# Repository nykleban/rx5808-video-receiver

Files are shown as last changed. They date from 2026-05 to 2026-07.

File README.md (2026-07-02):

# Smart FPV Analog RX & Spectral Analyzer

**Проєкт:** апаратно-програмний комплекс для прийому аналогового FPV-відеосигналу 5.8 GHz та сканування радіочастотного спектра в реальному часі.

---

## Про Проєкт

Цей репозиторій містить вихідний код прошивки, десктопного додатку та файли проєкту друкованої плати для розумного FPV-приймача. Система побудована на базі мікроконтролера **ATmega328P**, високочастотного модуля **RX5808** та розширеної системи керування живленням для забезпечення стабільних аналогових вимірювань.

Проєкт поєднує низькорівневе програмування вбудованих систем, розробку 4-шарової PCB з високими вимогами до розведення RF, силових та аналогових вузлів, а також десктопний аналізатор на Python. Проєкт розроблено в рамках інженерно-практичної роботи програми робототехніки Інституту ІТ та бізнесу.

Плата спроєктована в KiCad і замовлена через JLCPCB. На момент підготовки репозиторію плата ще не доставлена, тому в репозиторії подані проєктні матеріали: схема, PCB-layout, production-файли, 3D-рендери та скріншоти програмної частини.

---

## Основні Характеристики системи

### Hardware

- **RF-модуль:** приймач **RX5808 5.8 GHz** із керуванням через SPI для вибору частоти.
- **Мікроконтролер:** **ATmega328P** із зовнішнім кварцовим резонатором 16 MHz.
- **Power Management:** контролер заряду **Texas Instruments BQ25703A**, апаратний захист акумулятора **HY2120-CB**, шунти для вимірювання струму.
- **Інтерфейси:** **USB Type-C**, **CP2102N USB-to-UART**, торцевий **SMA edge-mount** роз'єм для FPV-антени.

### Software

- **Firmware C/C++:** прошивка для ATmega328P із керуванням RX5808 через SPI, зчитуванням RSSI через ADC, I2C-взаємодією з BQ25703A та serial logging.
- **Python GUI:** десктопний додаток для візуалізації RSSI в реальному часі та перевірки рівня сигналу на обраній частоті.

---

## Основні можливості

- прийом аналогового FPV-сигналу 5.8 GHz через RX5808;
- перемикання FPV-частот через SPI-керування RX5808;
- зчитування RSSI для оцінки рівня сигналу;
- виведення band, channel, frequency та RSSI через serial log;
- візуалізація RSSI в desktop analyzer у реальному часі;
- підготовлена 4-шарова PCB з окремими RF, MCU та power-management блоками;
- production package для виготовлення плати.

---

## Архітектура Друкованої Плати (PCB Layout)

Плата розроблена як 4-шарова PCB товщиною 1.6 мм з урахуванням суворих правил трасування:

1. **Ізоляція шумів:** силовий імпульсний блок з BQ25703A максимально віддалений від аналогової частини приймача RX5808.
2. **Розділення функціональних блоків:** RF, MCU, USB/UART та power-management частини винесені в окремі зони плати.
3. **Екранування:** GND-полігони використовуються для зменшення шумів і покращення стабільності аналогових вимірювань.
4. **Production-ready структура:** підготовлено BOM, positions, designators, IPC netlist і production archive для виготовлення плати.

---

## Firmware

Прошивка для ATmega328P реалізує:

- SPI-керування RX5808;
- вибір FPV-частоти;
- зчитування RSSI через ADC;
- I2C-взаємодію з power-management контролером;
- serial logging для перевірки каналу, частоти та RSSI.

Файл прошивки: `CODE/fpv_receiver.ino`

---

## Desktop analyzer

Python-додаток використовується для перегляду RSSI в реальному часі. Він дає змогу візуально порівнювати рівень сигналу на різних каналах і бачити стабільність прийому.

Використані технології: Python, PyQt5, pyqtgraph, pyserial, NumPy.

Файл додатку: `CODE/main.py`

---

## Структура репозиторію

```text
.
├── CODE/                         # firmware and desktop analyzer
│   ├── fpv_receiver.ino
│   └── main.py
├── IMAGES/                       # renders, schematics and analyzer screenshots
├── Custom_Libs/                  # custom KiCad symbols and footprints
├── production/                   # BOM, positions, designators, netlist
├── atmega328.kicad_pcb           # PCB layout
├── atmega328.kicad_sch           # main schematic
├── mcu_atmega_spi.kicad_sch      # MCU/SPI schematic block
├── rx5808_rf.kicad_sch           # RF schematic block
├── power_usb_battery_buck.kicad_sch
└── production.zip
```

---

## Візуальні матеріали

### PCB та схема

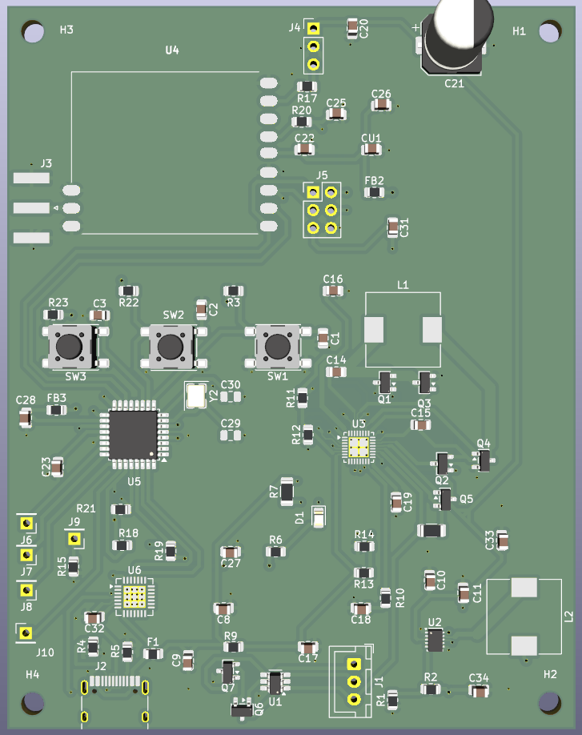
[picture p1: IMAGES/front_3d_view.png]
Front 3D view


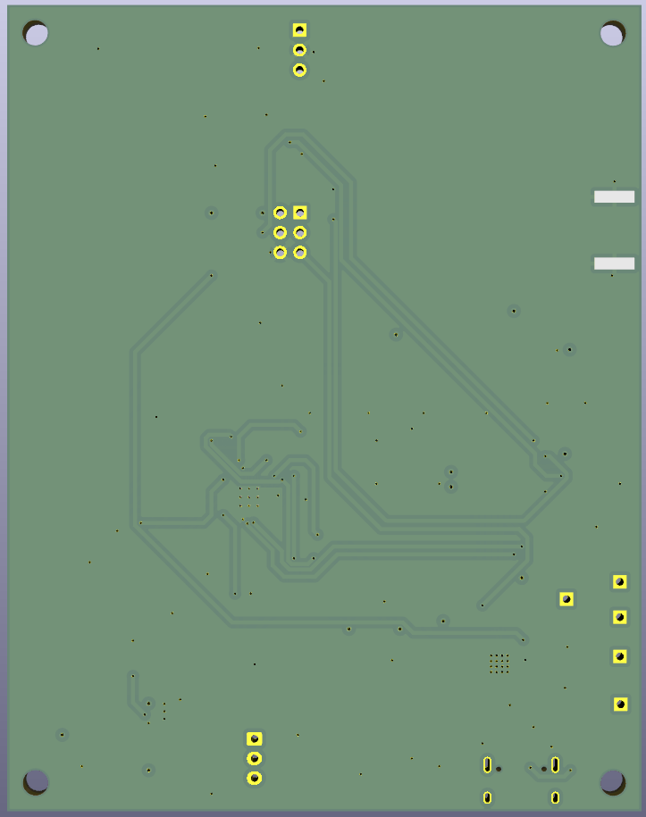
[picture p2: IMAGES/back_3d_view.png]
Back 3D view


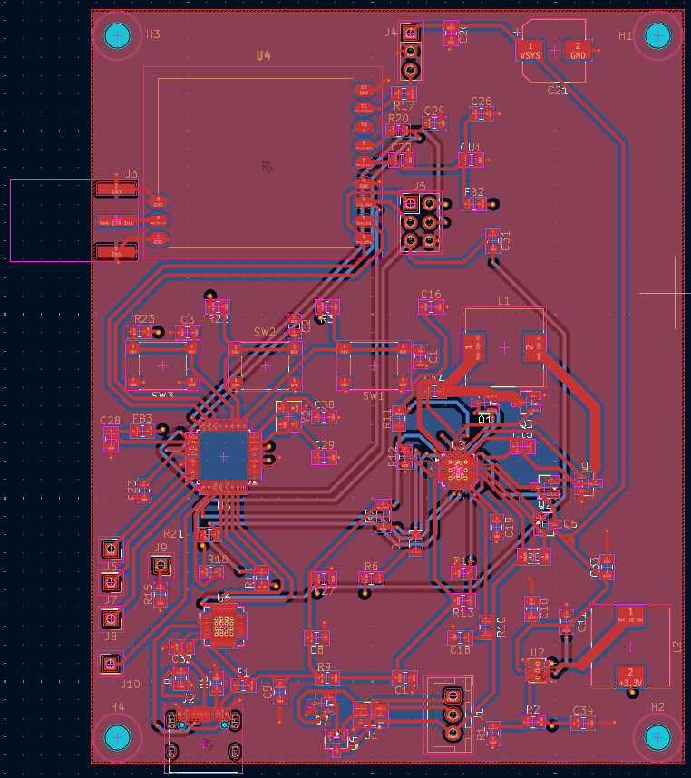
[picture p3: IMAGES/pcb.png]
PCB layout


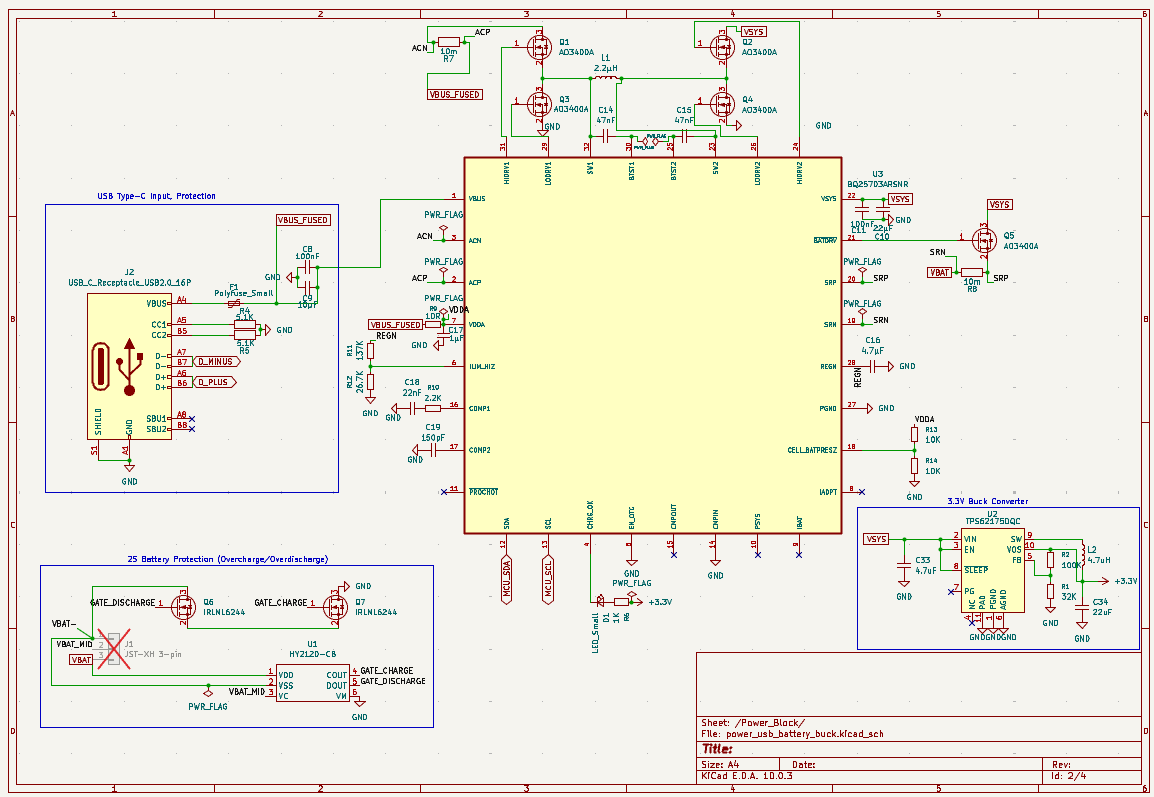
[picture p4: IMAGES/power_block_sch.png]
Power block schematic


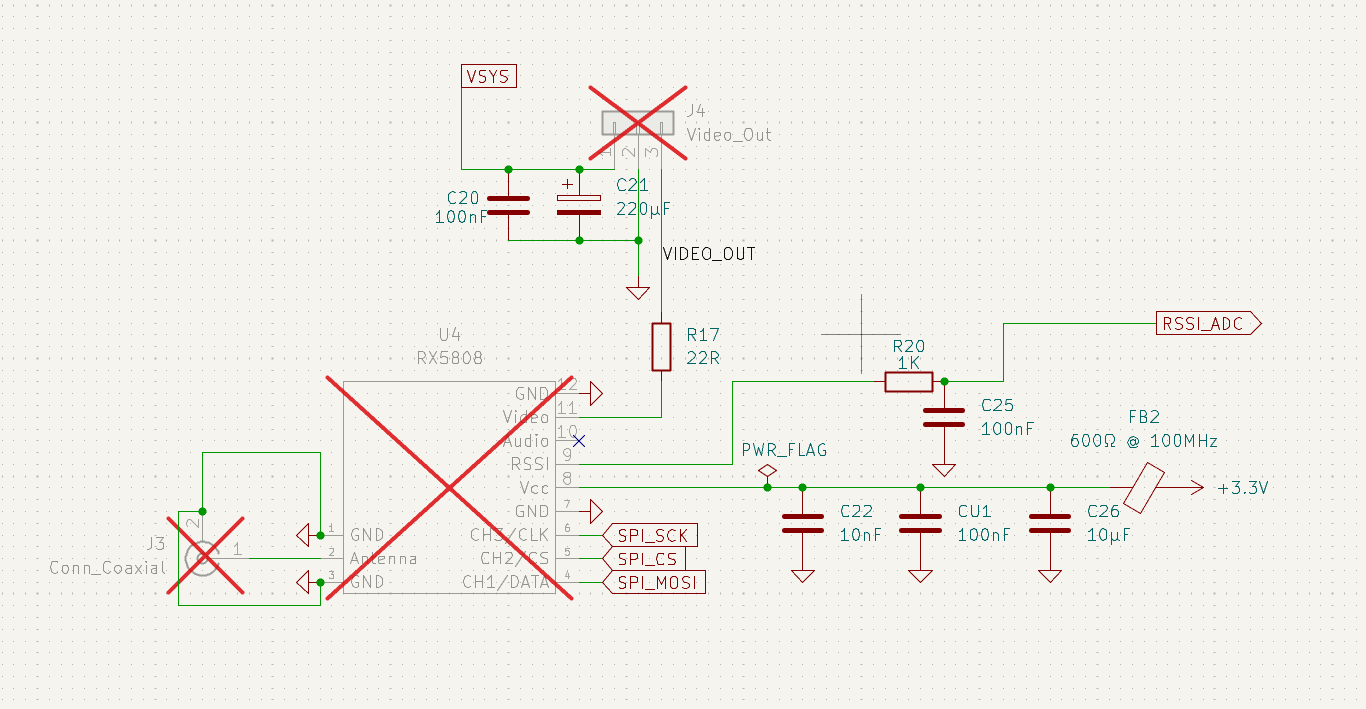
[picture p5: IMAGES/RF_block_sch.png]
RF block schematic


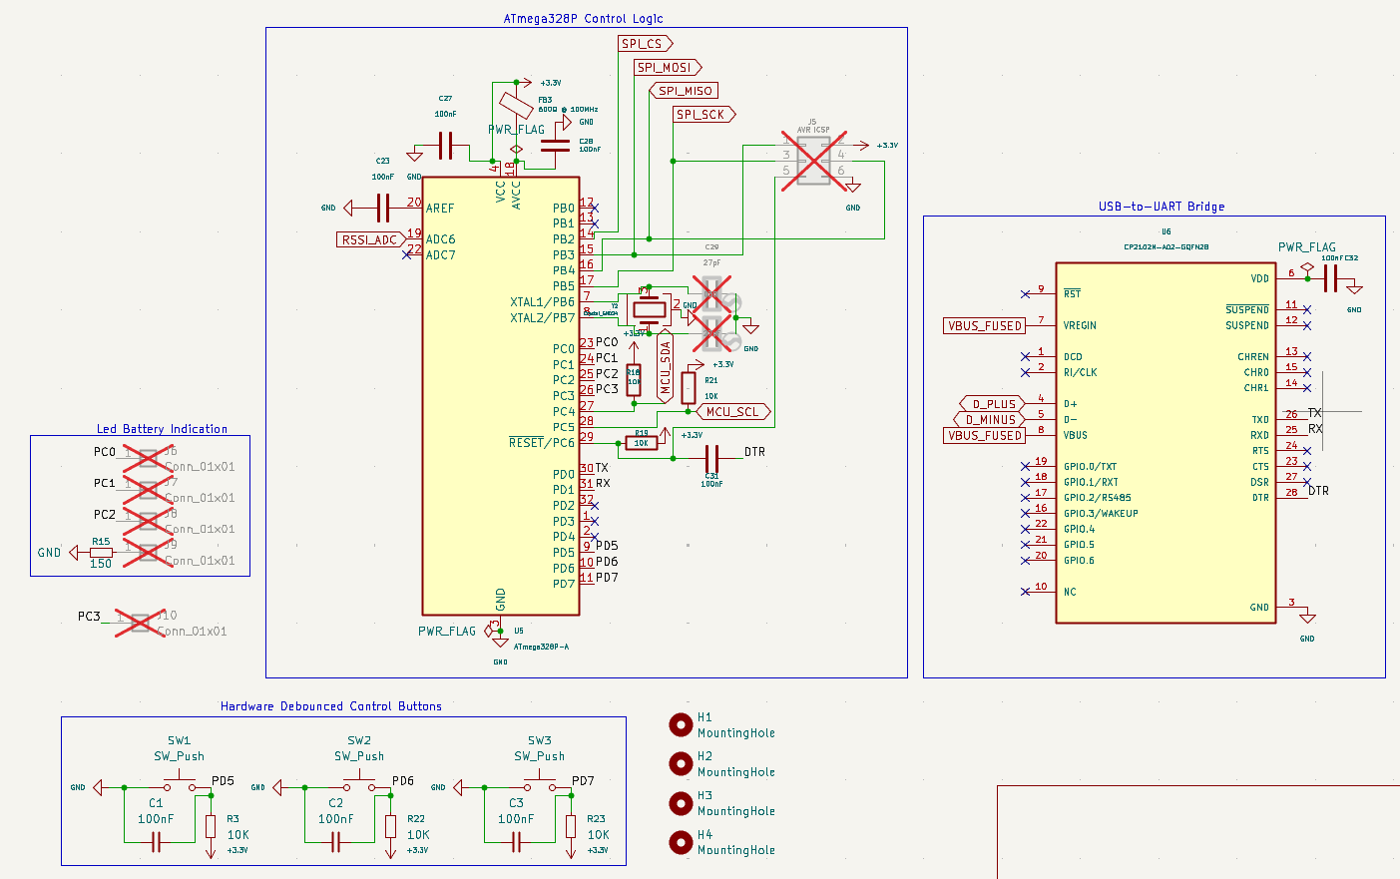
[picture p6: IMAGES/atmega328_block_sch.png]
ATmega328P block schematic


### RSSI analyzer

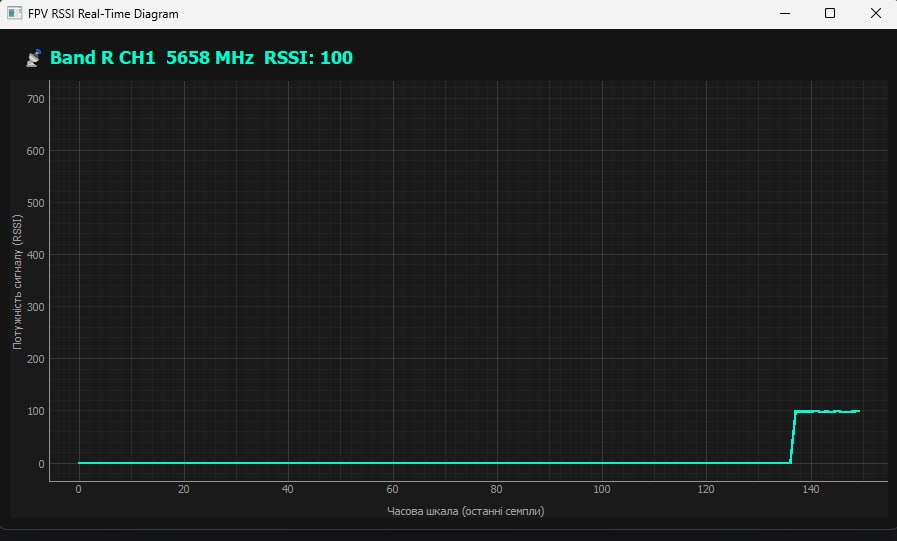
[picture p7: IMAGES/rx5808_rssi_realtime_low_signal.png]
Low signal RSSI


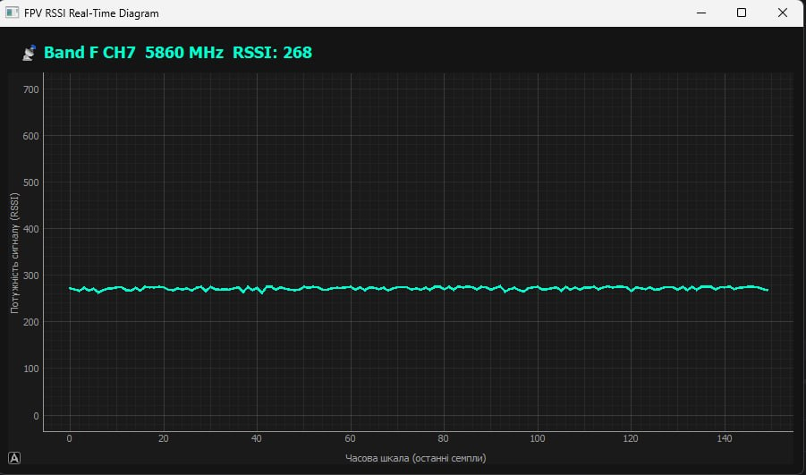
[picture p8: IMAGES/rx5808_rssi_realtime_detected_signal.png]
Detected signal RSSI


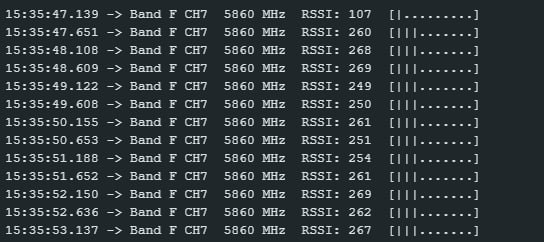
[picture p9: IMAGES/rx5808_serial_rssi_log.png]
Serial RSSI log


---

## Production files

Папка `production/` містить матеріали для виготовлення та перевірки плати:

- `bom.csv`;
- `positions.csv`;
- `designators.csv`;
- `netlist.ipc`;
- `atmega328.zip`.

Також у корені є `production.zip` як готовий архів production package.

---

## Поточний статус

- schematic design completed;
- 4-layer PCB layout completed;
- production files generated;
- PCB ordered through JLCPCB;
- firmware and desktop analyzer added to the repository;
- RSSI analyzer screenshots included.

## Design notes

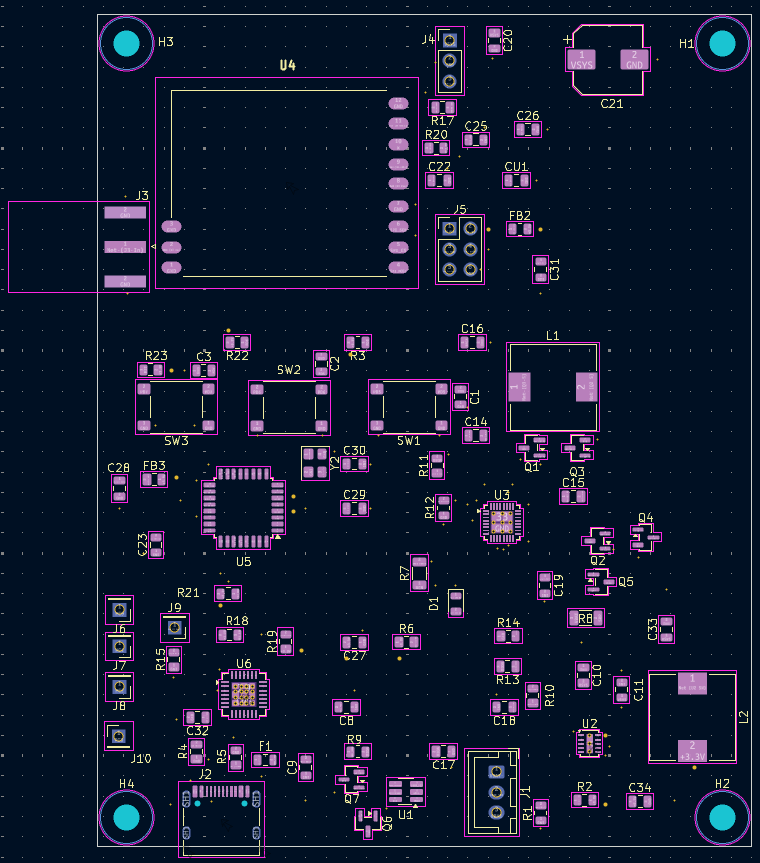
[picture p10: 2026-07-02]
IMAGES/pcb_without_traces.png

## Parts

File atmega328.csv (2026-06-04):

Reference | Value | Footprint | LCSC
C1,C2,C3,C8,C11,C20,C23,C25,C27,C28,C31,C32,CU1 | 100nF | Capacitor_SMD:C_0805_2012Metric | C1711
C9,C26 | 10µF | Capacitor_SMD:C_0805_2012Metric | C7469956
C10 | 22µF | Capacitor_SMD:C_0805_2012Metric | C602037
C14,C15 | 47nF | Capacitor_SMD:C_0805_2012Metric | C53134
C16 | 4.7µF | Capacitor_SMD:C_0805_2012Metric | C98195
C17 | 1µF | Capacitor_SMD:C_0805_2012Metric | C1791
C18 | 22nF | Capacitor_SMD:C_0805_2012Metric | C1729
C19 | 150pF | Capacitor_SMD:C_0805_2012Metric | C2319426
C21 | 220µF | Capacitor_SMD:CP_Elec_8x10 | C136294
C22 | 10nF | Capacitor_SMD:C_0805_2012Metric | C1710
C33 | 4.7uF | Capacitor_SMD:C_0805_2012Metric | C98195
C34 | 22uF | Capacitor_SMD:C_0805_2012Metric | C602037
D1 | LED_Small | LED_SMD:LED_0805_2012Metric | C84260
F1 | Polyfuse_Small | Fuse:Fuse_0805_2012Metric | C2840556
FB2,FB3 | 600Ω @ 100MHz | Resistor_SMD:R_0805_2012Metric | C21519
J1 | JST-XH 3-pin | Connector_JST:JST_XH_B3B-XH-A_1x03_P2.50mm_Vertical
J2 | USB_C_Receptacle_USB2.0_16P | Connector_USB:USB_C_Receptacle_HRO_TYPE-C-31-M-12 | C2988369
J3 | Conn_Coaxial | Connector_Coaxial:SMA_Amphenol_132289_EdgeMount | C20415780
J4 | Video_Out | Connector_PinHeader_2.54mm:PinHeader_1x03_P2.54mm_Vertical
J5 | AVR ICSP | Connector_PinHeader_2.54mm:PinHeader_2x03_P2.54mm_Vertical
J6,J7,J8,J9,J10 | Conn_01x01 | Connector_PinHeader_2.54mm:PinHeader_1x01_P2.54mm_Vertical
L1 | 2.2µH | Inductor_SMD:L_10.4x10.4_H4.8 | C10164
L2 | 4.7uH | Inductor_SMD:L_10.4x10.4_H4.8 | C19633496
Q1,Q2,Q3,Q4,Q5 | AO3400A | Package_TO_SOT_SMD:SOT-23 | C20917
Q6,Q7 | IRLML6244 | Package_TO_SOT_SMD:SOT-23 | C5364311
R1 | 32K | Resistor_SMD:R_0805_2012Metric | C6460768
R2 | 100K | Resistor_SMD:R_0805_2012Metric | C441992
R3,R13,R14,R18,R19,R21,R22,R23 | 10K | Resistor_SMD:R_0805_2012Metric | C543567
R4,R5 | 5.1K | Resistor_SMD:R_0805_2012Metric | C491151
R6 | 1K | Resistor_SMD:R_0805_2012Metric | C844939
R7,R8 | 10m | Resistor_SMD:R_1206_3216Metric | C308574
R9 | 10R | Resistor_SMD:R_0805_2012Metric | C844598
R10 | 2.2K | Resistor_SMD:R_0805_2012Metric | C441982
R11 | 137K | Resistor_SMD:R_0805_2012Metric | C203741
R12 | 26.7K | Resistor_SMD:R_0805_2012Metric | C153307
R15 | 150 | Resistor_SMD:R_0805_2012Metric | C2933324
R17 | 22R | Resistor_SMD:R_0805_2012Metric | C441970
R20 | 1К | Resistor_SMD:R_0805_2012Metric | C844939
SW1,SW2,SW3 | SW_Push | Button_Switch_SMD:SW_SPST_PTS645Sx43SMTR92 | C2834918
U1 | HY2120-CB | Package_TO_SOT_SMD:SOT-23-6_Handsoldering | C116509
U2 | TPS62175DQC | Package_SON:WSON-10-1EP_2x3mm_P0.5mm_EP0.84x2.4mm_ThermalVias | C32097
U3 | BQ25703ARSNR | Package_DFN_QFN:Texas_RSN_WQFN-32-1EP_4x4mm_P0.4mm_EP2.8x2.8mm_ThermalVias | C188229
U4 | RX5808 | RF_Antenna:RX5808
U5 | ATmega328P-A | Package_QFP:TQFP-32_7x7mm_P0.8mm | C14877
U6 | CP2102N-A02-GQFN28 | Package_DFN_QFN:QFN-28-1EP_5x5mm_P0.5mm_EP3.1x3.1mm_ThermalVias | C964632
Y2 | Crystal_GND24 | Crystal:Crystal_SMD_3225-4Pin_3.2x2.5mm | C7275095

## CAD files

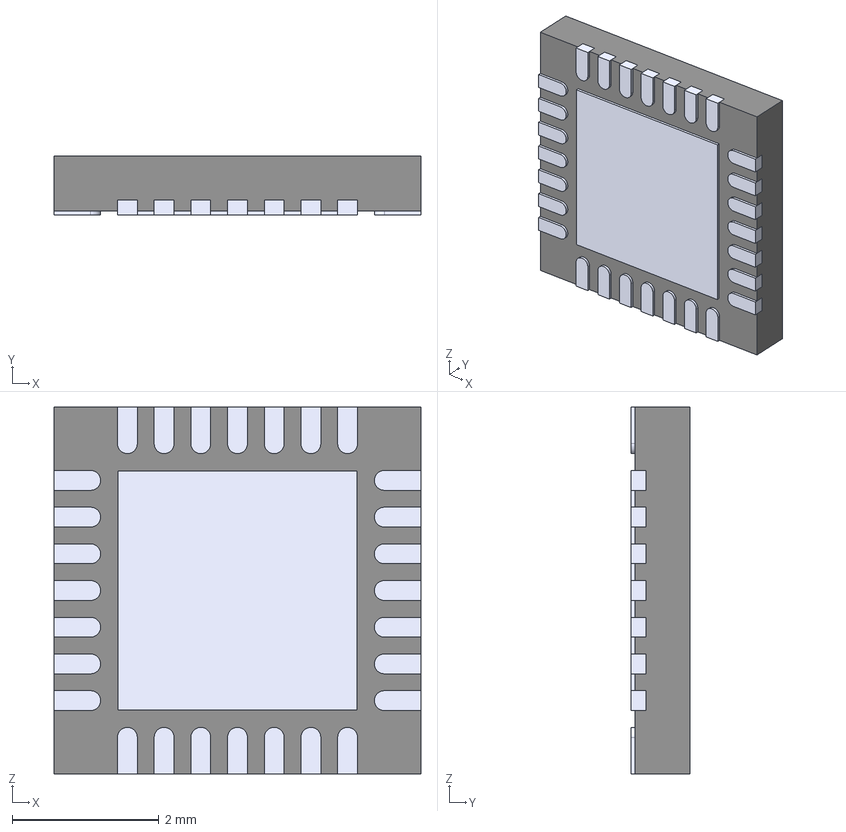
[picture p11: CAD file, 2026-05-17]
CP2102N-A02-GQFN28.step
5.00 x 0.8 x 5.00 mm
Body_Solid1
Body001_Solid1
Array_Solid1 x 7
Array001_Solid2 x 6
Body002_Solid1
Array002_Solid1 x 7
Array003_Solid2 x 6
Body003_Solid1
Body004_Solid1

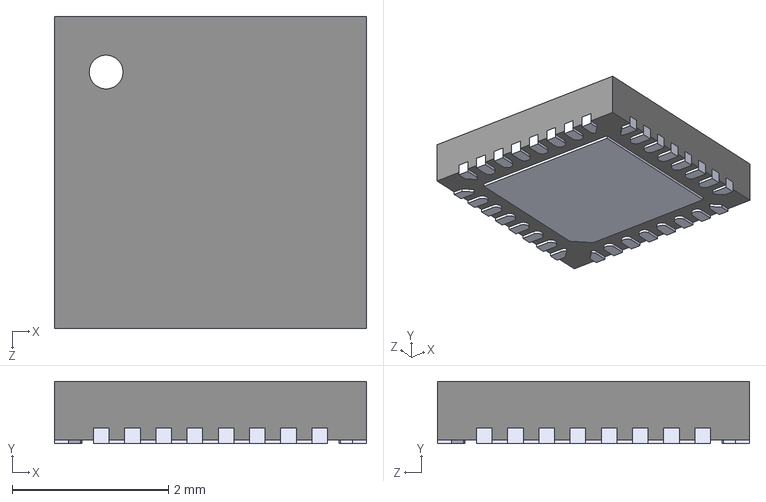
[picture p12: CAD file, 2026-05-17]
Custom_Libs/BQ25703ARSNR.step
4.00 x 0.8 x 4.00 mm

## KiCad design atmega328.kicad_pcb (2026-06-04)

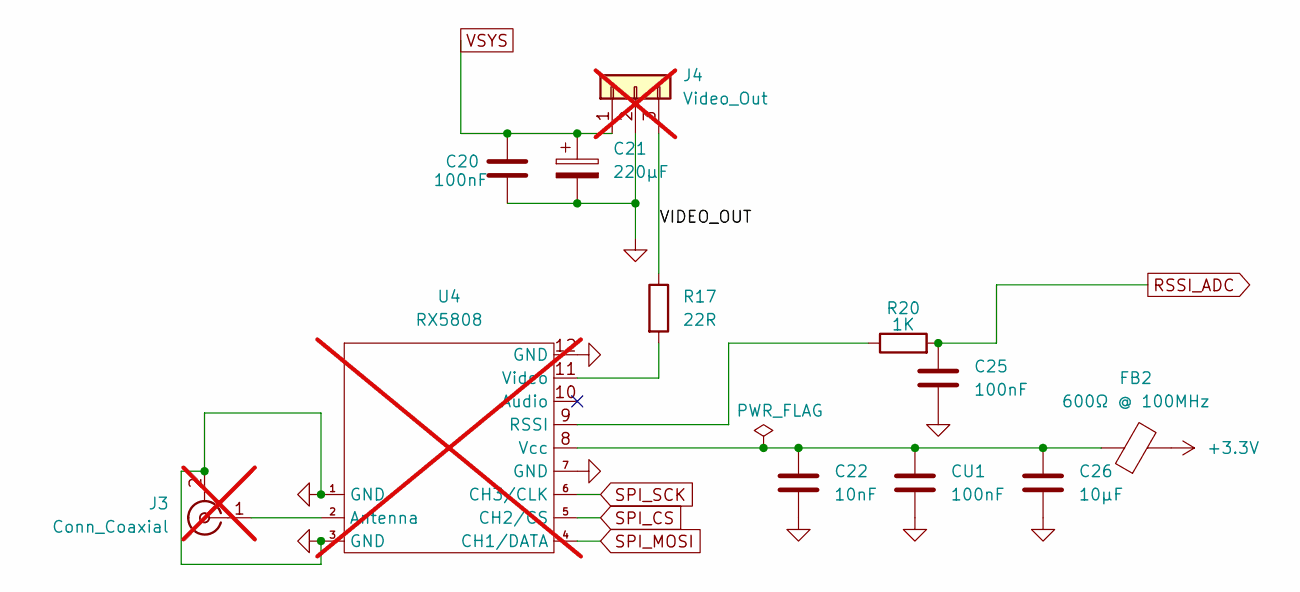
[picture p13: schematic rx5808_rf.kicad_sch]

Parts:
C20, C25: 100nF; C_0805_2012Metric; LCSC C1711
C21: 220µF; CP_Elec_8x10; LCSC C136294
C22: 10nF; C_0805_2012Metric; LCSC C1710
C26: 10µF; C_0805_2012Metric; LCSC C7469956
CU1: 100nF; C_0805_2012Metric; LCSC C1711
FB2: 600Ω @ 100MHz; R_0805_2012Metric; LCSC C21519
J3: Conn_Coaxial; SMA_Amphenol_132289_EdgeMount; LCSC C20415780; not fitted
J4: Video_Out; PinHeader_1x03_P2.54mm_Vertical; not fitted
R17: 22R; R_0805_2012Metric; LCSC C441970
R20: 1К; R_0805_2012Metric; LCSC C844939
U4: RX5808; not fitted

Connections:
+3.3V: FB2.2; also elsewhere on the board
/RX5808/VIDEO_OUT: J4.3, R17.1
GND: C20.2, C21.2, C22.2, C25.2, C26.2, CU1.2, J3.2 (Ext), J4.2, U4.1 (GND), U4.3 (GND), U4.7 (GND), U4.12 (GND); also elsewhere on the board
unnamed: J3.1 (In), U4.2 (Antenna)
unnamed: R20.1, U4.9 (RSSI)
unnamed: C22.1, C26.1, CU1.1, FB2.1, U4.8 (Vcc)
unnamed: R17.2, U4.11 (Video)
RSSI_ADC: C25.1, R20.2; also elsewhere on the board
SPI_CS: U4.5 (CH2/CS); also elsewhere on the board
SPI_MOSI: U4.4 (CH1/DATA); also elsewhere on the board
SPI_SCK: U4.6 (CH3/CLK); also elsewhere on the board
VSYS: C20.1, C21.1, J4.1; also elsewhere on the board

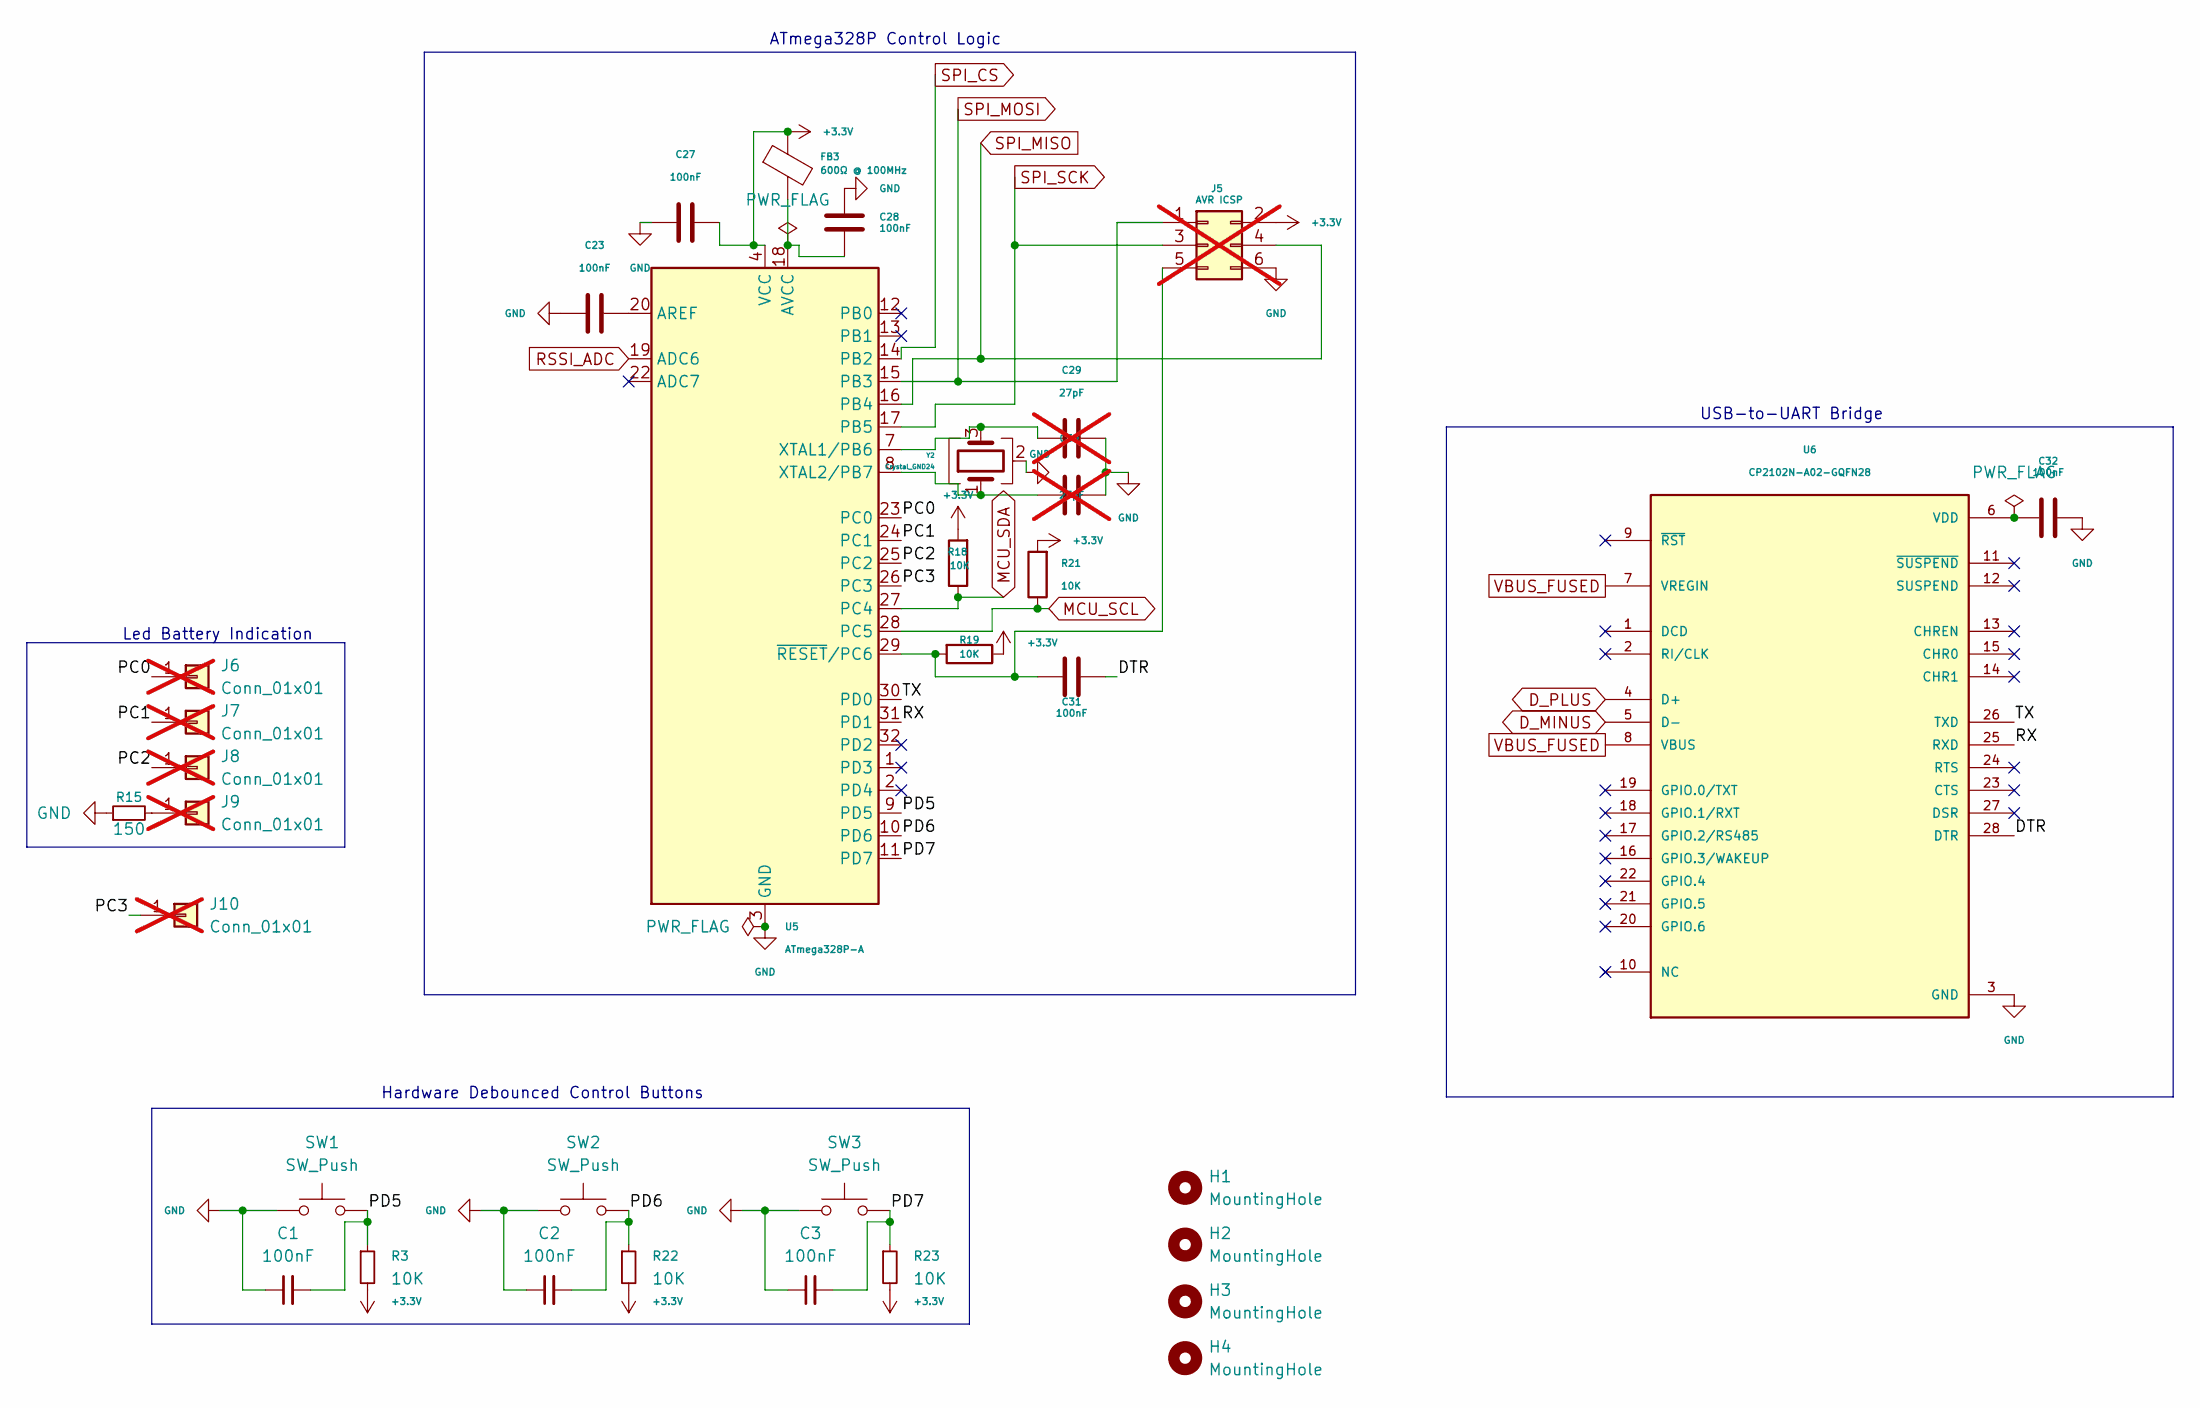
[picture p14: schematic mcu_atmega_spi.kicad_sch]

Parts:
C1, C2, C3, C23, C27, C28, C31, C32: 100nF; C_0805_2012Metric; LCSC C1711
C29, C30: 27pF; C_0805_2012Metric; LCSC C472840; not fitted
FB3: 600Ω @ 100MHz; R_0805_2012Metric; LCSC C21519
H1, H2, H3, H4: MountingHole; MountingHole_3.2mm_M3
J5: AVR ICSP; PinHeader_2x03_P2.54mm_Vertical; not fitted
J6, J7, J8, J9, J10: Conn_01x01; PinHeader_1x01_P2.54mm_Vertical; not fitted
R3, R18, R19, R21, R22, R23: 10K; R_0805_2012Metric; LCSC C543567
R15: 150; R_0805_2012Metric; LCSC C2933324
SW1, SW2, SW3: SW_Push; SW_SPST_PTS645Sx43SMTR92; LCSC C2834918
U5: ATmega328P-A; TQFP-32_7x7mm_P0.8mm; LCSC C14877
U6: CP2102N-A02-GQFN28; QFN-28-1EP_5x5mm_P0.5mm_EP3.1x3.1mm_ThermalVias; PARTREV 1.5; LCSC C964632
Y2: Crystal_GND24; Crystal_SMD_3225-4Pin_3.2x2.5mm; LCSC C7275095

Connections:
+3.3V: C27.2, FB3.1, J5.2, R3.2, R18.2, R19.1, R21.2, R22.2, R23.2, U5.4 (VCC), U5.6 (VCC); also elsewhere on the board
/MCU_Block/DTR: C31.2, U6.28 (DTR)
/MCU_Block/PC0: J6.1 (Pin_1_1), U5.23 (PC0)
/MCU_Block/PC1: J7.1 (Pin_1_1), U5.24 (PC1)
/MCU_Block/PC2: J8.1 (Pin_1_1), U5.25 (PC2)
/MCU_Block/PC3: J10.1 (Pin_1_1), U5.26 (PC3)
/MCU_Block/PD5: C1.2, R3.1, SW1.2, U5.9 (PD5)
/MCU_Block/PD6: C2.2, R22.1, SW2.2, U5.10 (PD6)
/MCU_Block/PD7: C3.2, R23.1, SW3.2, U5.11 (PD7)
/MCU_Block/RX: U5.31 (PD1), U6.25 (RXD)
/MCU_Block/TX: U5.30 (PD0), U6.26 (TXD)
D_MINUS: U6.5 (D-); also elsewhere on the board
D_PLUS: U6.4 (D+); also elsewhere on the board
GND: C1.1, C2.1, C3.1, C23.1, C27.1, C28.2, C29.2, C30.2, C32.2, J5.6, R15.1, SW1.1, SW2.1, SW3.1, U5.3 (GND), U5.5 (GND), U5.21 (GND), U6.3 (GND), U6.29 (GND), Y2.2 (G), Y2.4 (G); also elsewhere on the board
MCU_SCL: R21.1, U5.28 (PC5); also elsewhere on the board
MCU_SDA: R18.1, U5.27 (PC4); also elsewhere on the board
unnamed: C31.1, J5.5, R19.2, U5.29 (~RESET/PC6)
unnamed: J9.1 (Pin_1_1), R15.2
unnamed: C23.2, U5.20 (AREF)
unnamed: C28.1, FB3.2, U5.18 (AVCC)
unnamed: C29.1, U5.7 (XTAL1/PB6), Y2.3
unnamed: C30.1, U5.8 (XTAL2/PB7), Y2.1
unnamed: C32.1, U6.6 (VDD)
RSSI_ADC: U5.19 (ADC6); also elsewhere on the board
SPI_CS: U5.14 (PB2); also elsewhere on the board
SPI_MISO: J5.4, U5.16 (PB4)
SPI_MOSI: J5.1, U5.15 (PB3); also elsewhere on the board
SPI_SCK: J5.3, U5.17 (PB5); also elsewhere on the board
VBUS_FUSED: U6.7 (VREGIN), U6.8 (VBUS); also elsewhere on the board

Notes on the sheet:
ATmega328P Control Logic
Hardware Debounced Control Buttons
Led Battery Indication
USB-to-UART Bridge

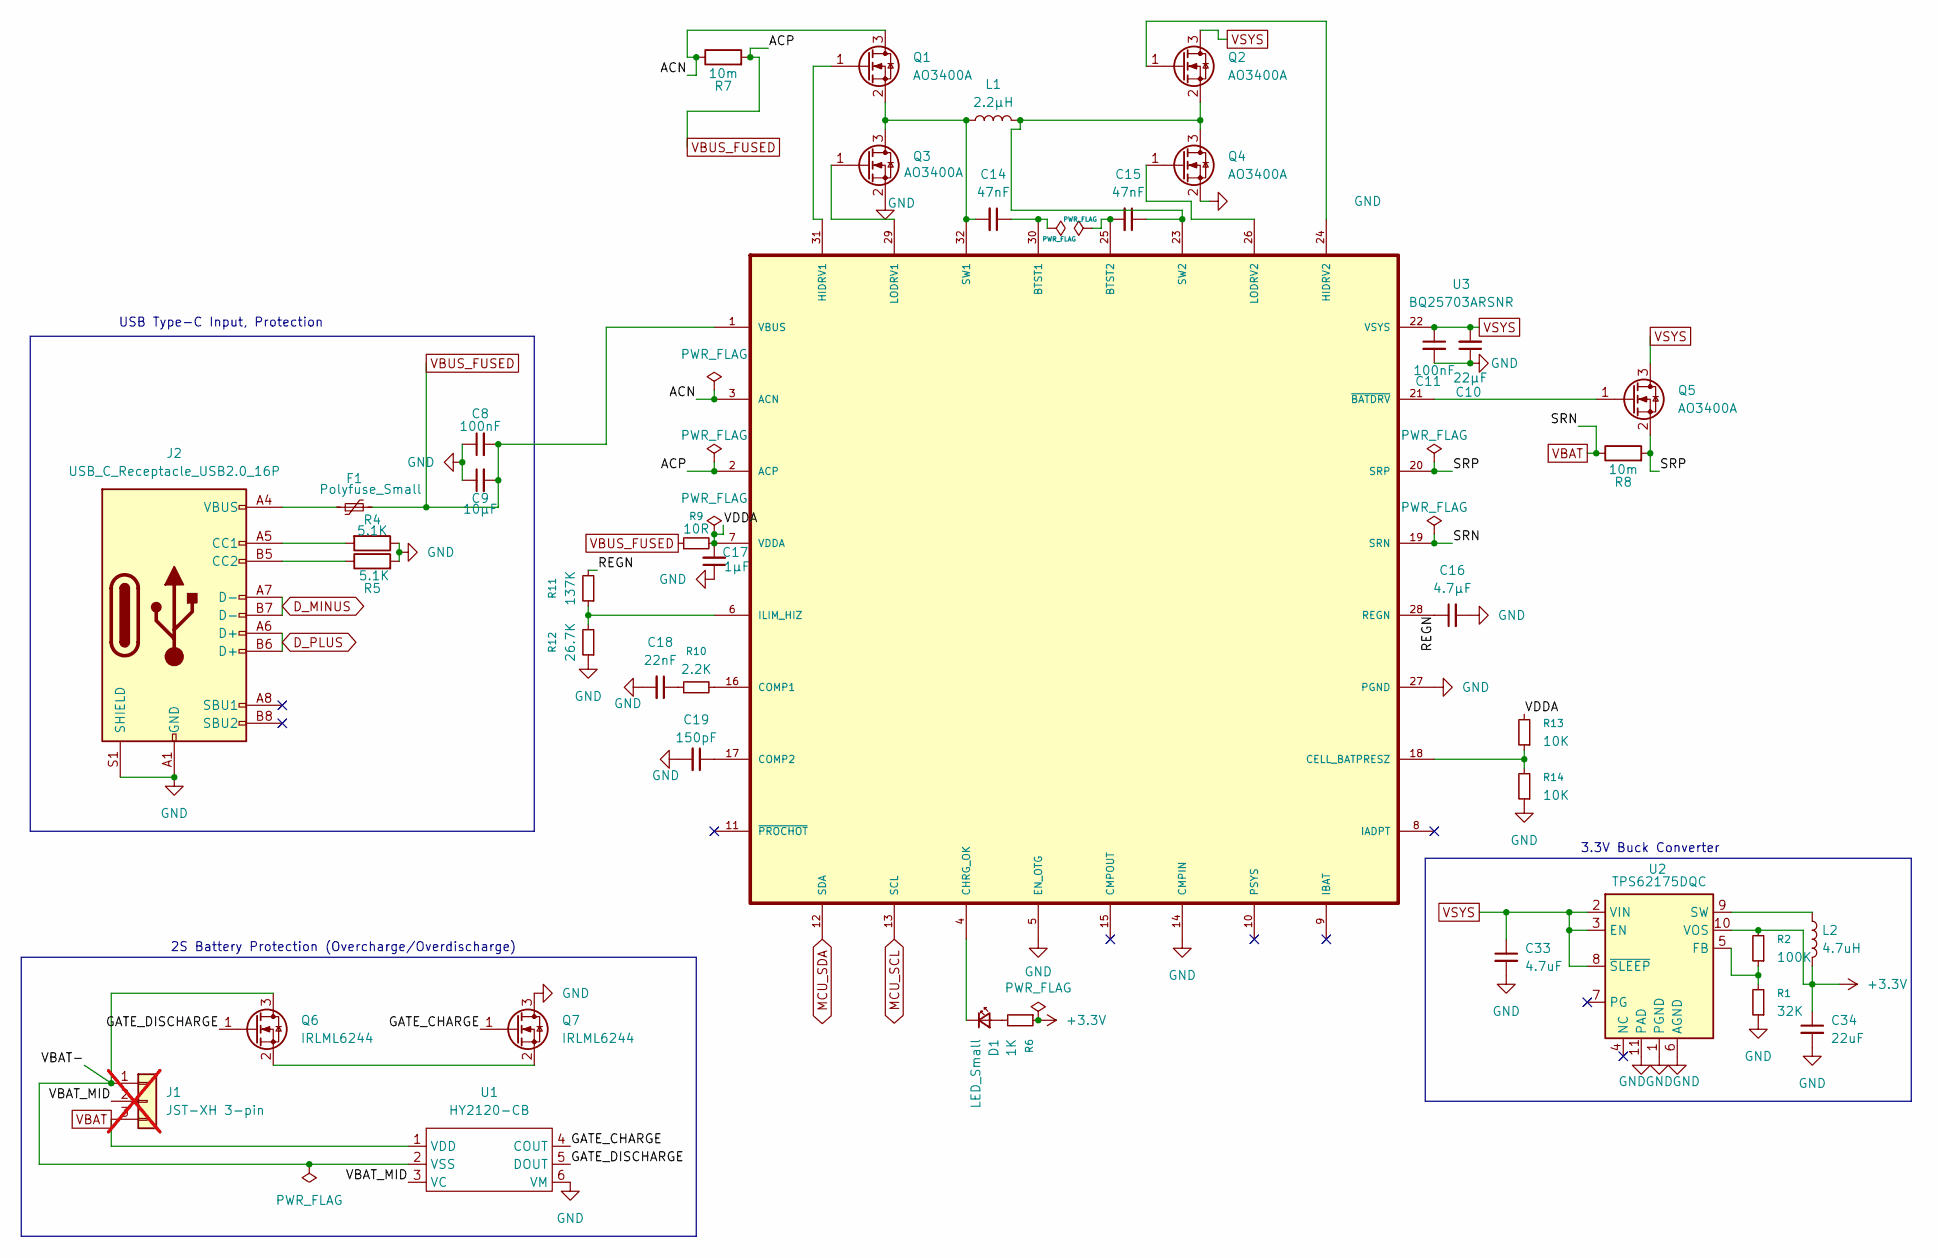
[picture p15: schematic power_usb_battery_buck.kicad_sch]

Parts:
C8, C11: 100nF; C_0805_2012Metric; LCSC C1711
C9: 10µF; C_0805_2012Metric; LCSC C7469956
C10: 22µF; C_0805_2012Metric; LCSC C602037
C14, C15: 47nF; C_0805_2012Metric; LCSC C53134
C16: 4.7µF; C_0805_2012Metric; LCSC C98195
C17: 1µF; C_0805_2012Metric; LCSC C1791
C18: 22nF; C_0805_2012Metric; LCSC C1729
C19: 150pF; C_0805_2012Metric; LCSC C2319426
C33: 4.7uF; C_0805_2012Metric; LCSC C98195
C34: 22uF; C_0805_2012Metric; LCSC C602037
D1: LED_Small; LED_0805_2012Metric; LCSC C84260
F1: Polyfuse_Small; Fuse_0805_2012Metric; LCSC C2840556
J1: JST-XH 3-pin; JST_XH_B3B-XH-A_1x03_P2.50mm_Vertical; not fitted
J2: USB_C_Receptacle_USB2.0_16P; USB_C_Receptacle_HRO_TYPE-C-31-M-12; LCSC C2988369
L1: 2.2µH; L_10.4x10.4_H4.8; LCSC C10164
L2: 4.7uH; L_10.4x10.4_H4.8; LCSC C19633496
Q1, Q2, Q3, Q4, Q5: AO3400A; SOT-23; LCSC C20917
Q6, Q7: IRLML6244; SOT-23; LCSC C5364311
R1: 32K; R_0805_2012Metric; LCSC C6460768
R2: 100K; R_0805_2012Metric; LCSC C441992
R4, R5: 5.1K; R_0805_2012Metric; LCSC C491151
R6: 1K; R_0805_2012Metric; LCSC C844939
R7, R8: 10m; R_1206_3216Metric; LCSC C308574
R9: 10R; R_0805_2012Metric; LCSC C844598
R10: 2.2K; R_0805_2012Metric; LCSC C441982
R11: 137K; R_0805_2012Metric; LCSC C203741
R12: 26.7K; R_0805_2012Metric; LCSC C153307
R13, R14: 10K; R_0805_2012Metric; LCSC C543567
U1: HY2120-CB; SOT-23-6_Handsoldering; LCSC C116509
U2: TPS62175DQC; WSON-10-1EP_2x3mm_P0.5mm_EP0.84x2.4mm_ThermalVias; LCSC C32097
U3: BQ25703ARSNR; Texas_RSN_WQFN-32-1EP_4x4mm_P0.4mm_EP2.8x2.8mm_ThermalVias; LCSC C188229

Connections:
+3.3V: C34.1, L2.2, R2.2, R6.1, U2.10 (VOS); also elsewhere on the board
/Power_Block/ACN: Q1.3 (D), R7.1, U3.3 (ACN)
/Power_Block/GATE_CHARGE: Q7.1 (G), U1.4 (COUT)
/Power_Block/GATE_DISCHARGE: Q6.1 (G), U1.5 (DOUT)
/Power_Block/REGN: C16.1, R11.2, U3.28 (REGN)
/Power_Block/SRP: Q5.2 (S), R8.2, U3.20 (SRP)
/Power_Block/VBAT-: J1.1, Q6.3 (D), U1.2 (VSS)
/Power_Block/VBAT_MID: J1.2, U1.3 (VC)
/Power_Block/VDDA: C17.2, R9.2, R13.2, U3.7 (VDDA)
D_MINUS: J2.A7 (D-), J2.B7 (D-); also elsewhere on the board
D_PLUS: J2.A6 (D+), J2.B6 (D+); also elsewhere on the board
GND: C8.1, C9.1, C10.1, C11.2, C16.2, C17.1, C18.2, C19.2, C33.2, C34.2, J2.A1 (GND), J2.A12 (GND), J2.B1 (GND), J2.B12 (GND), J2.S1 (SHIELD), Q3.2 (S), Q4.2 (S), Q7.3 (D), R1.1, R4.1, R5.2, R12.1, R14.1, U1.6 (VM), U2.1 (PGND), U2.6 (AGND), U2.11 (PAD), U3.5 (EN_OTG), U3.14 (CMPIN), U3.27 (PGND), U3.33 (PGND); also elsewhere on the board
MCU_SCL: U3.13 (SCL); also elsewhere on the board
MCU_SDA: U3.12 (SDA); also elsewhere on the board
unnamed: C18.1, R10.1
unnamed: D1.2 (A), R6.2
unnamed: D1.1 (K), U3.4 (CHRG_OK)
unnamed: F1.1, J2.A4 (VBUS), J2.A9 (VBUS), J2.B4 (VBUS), J2.B9 (VBUS)
unnamed: J2.A5 (CC1), R4.2
unnamed: J2.B5 (CC2), R5.1
unnamed: Q1.1 (G), U3.31 (HIDRV1)
unnamed: C14.2, L1.1, Q1.2 (S), Q3.3 (D), U3.32 (SW1)
unnamed: Q2.1 (G), U3.24 (HIDRV2)
unnamed: C15.1, L1.2, Q2.2 (S), Q4.3 (D), U3.23 (SW2)
unnamed: Q3.1 (G), U3.29 (LODRV1)
unnamed: Q4.1 (G), U3.26 (LODRV2)
unnamed: Q5.1 (G), U3.21 (~BATDRV)
unnamed: Q6.2 (S), Q7.2 (S)
unnamed: R1.2, R2.1, U2.5 (FB)
unnamed: L2.1, U2.9 (SW)
unnamed: C14.1, U3.30 (BTST1)
unnamed: C15.2, U3.25 (BTST2)
unnamed: R13.1, R14.2, U3.18 (CELL_BATPRESZ)
unnamed: R10.2, U3.16 (COMP1)
unnamed: C19.1, U3.17 (COMP2)
unnamed: R11.1, R12.2, U3.6 (ILIM_HIZ)
VBAT: J1.3, R8.1, U1.1 (VDD), U3.19 (SRN)
VBUS_FUSED: C8.2, C9.2, F1.2, R7.2, R9.1, U3.1 (VBUS), U3.2 (ACP); also elsewhere on the board
VSYS: C10.2, C11.1, C33.1, Q2.3 (D), Q5.3 (D), U2.2 (VIN), U2.3 (EN), U2.8 (~SLEEP), U3.22 (VSYS); also elsewhere on the board

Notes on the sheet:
3.3V Buck Converter
USB Type-C Input, Protection
2S Battery Protection (Overcharge/Overdischarge)

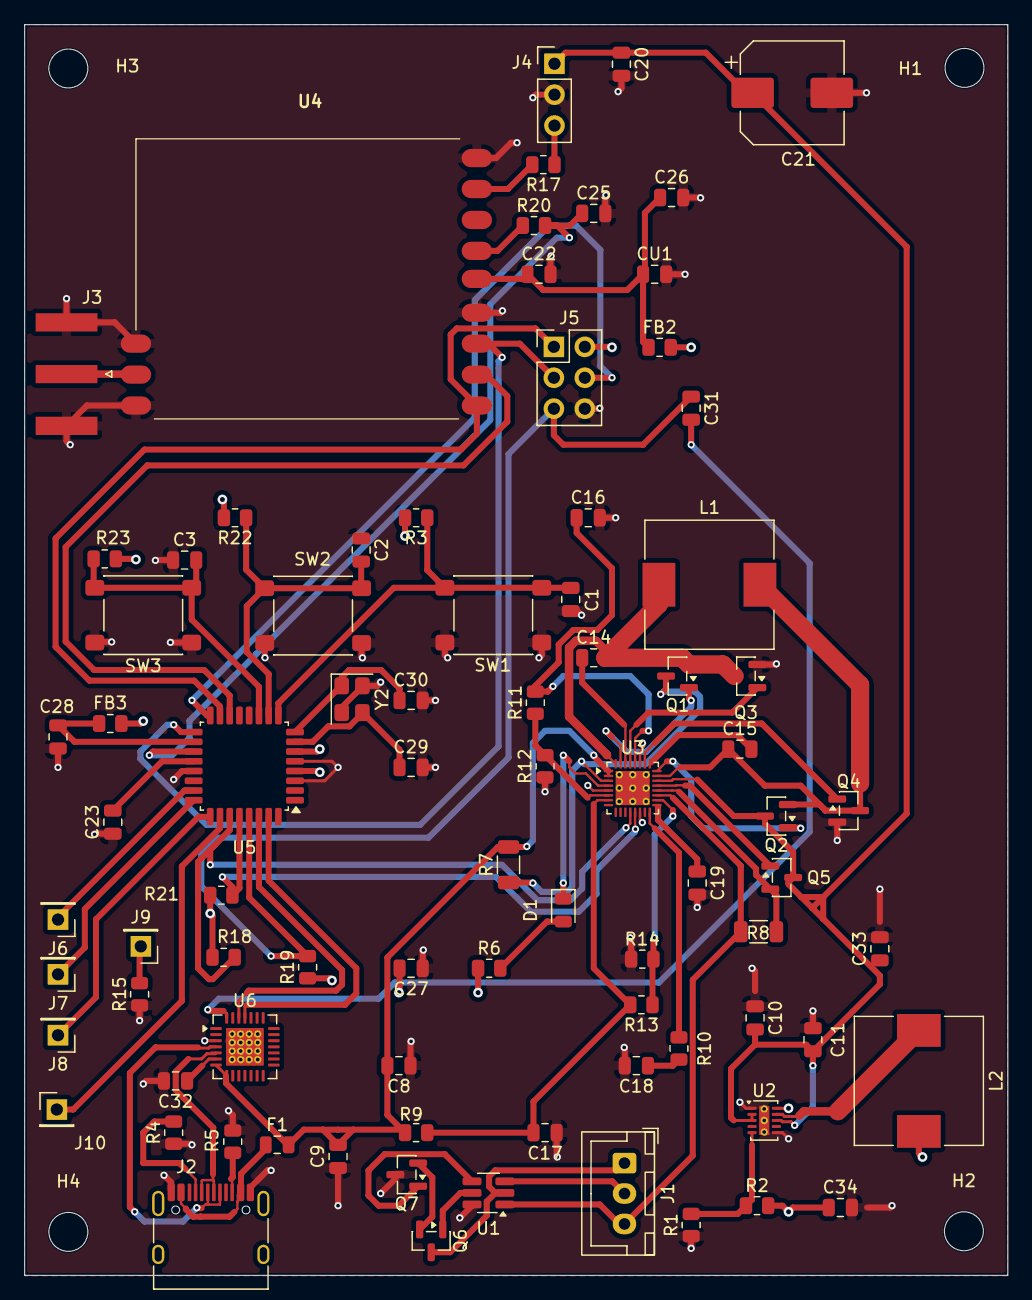
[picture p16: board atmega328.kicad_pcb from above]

Board: 4 copper layers, 80.7 x 102.7 mm, 87 parts (0 on the bottom side), 66 nets.

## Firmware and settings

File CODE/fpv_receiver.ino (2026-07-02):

/*
 * =============================================================
 *  FPV Відеоприймач RX5808 + ATmega328P
 *  Кастомна плата — Прошивка v1.0
 * =============================================================
 *
 *  АПАРАТНЕ ПІДКЛЮЧЕННЯ (згідно схеми):
 *  ─────────────────────────────────────
 *  RX5808 CH1/DATA  → PB3 (D11) — SPI_MOSI (bit-bang)
 *  RX5808 CH2/CS    → PB2 (D10) — SPI_CS
 *  RX5808 CH3/CLK   → PB5 (D13) — SPI_SCK
 *  RX5808 RSSI      → ADC6 (A6) — Аналоговий вхід
 *
 *  SW1 (Канал ▲)    → PD5 (D5)  — INPUT_PULLUP (активний LOW)
 *  SW2 (Канал ▼)    → PD6 (D6)  — INPUT_PULLUP (активний LOW)
 *  SW3 (Автоскан)   → PD7 (D7)  — INPUT_PULLUP (активний LOW)
 *
 *  LED індикація зарядки → PC3 (через R15 150Ω) — поки не використовується МК
 *
 *  I2C (BQ25703A зарядник) → PC4/SDA, PC5/SCL
 *  BQ25703A I2C адреса: 0x6B
 *
 *  UART (CP2102N) → PD0/RX, PD1/TX — для Serial Monitor
 *
 * =============================================================
 *  ЛОГІКА КЕРУВАННЯ:
 *  SW1 — наступний канал (1→2→...→8→1)
 *  SW2 — попередній канал (8→7→...→1→8)
 *  SW3 — автосканування (знаходить канал з найсильнішим RSSI)
 *
 *  Поточний канал та RSSI виводяться в Serial Monitor
 *  (115200 baud) через USB (CP2102N).
 * =============================================================
 */

#include <Wire.h>

// ─── ПІНИ ────────────────────────────────────────────────────
#define PIN_SPI_MOSI   11   // PB3
#define PIN_SPI_CS     10   // PB2
#define PIN_SPI_SCK    13   // PB5
#define PIN_RSSI       A6   // ADC6

#define PIN_BTN_UP      5   // PD5 — Канал ▲
#define PIN_BTN_DOWN    6   // PD6 — Канал ▼
#define PIN_BTN_SCAN    7   // PD7 — Автоскан

// ─── BQ25703A I2C ────────────────────────────────────────────
#define BQ25703A_ADDR       0x6B
// Регістри BQ25703A (16-бітні, little-endian)
#define REG_ADCVBAT_MSB     0x2B  // Напруга батареї (старший байт)
#define REG_ADCVBAT_LSB     0x2A  // Напруга батареї (молодший байт)
#define REG_ADC_OPTION      0x3A  // Увімкнення ADC вимірювань
#define REG_CHARGE_OPTION0  0x00  // Головні налаштування

// ─── ТАБЛИЦЯ ЧАСТОТ RX5808 ───────────────────────────────────
/*
 * Формат: кожен запис — 20-бітне число для передачі по SPI.
 * Синтез: F = (N * 32 + M) * 2, де N — ціла частина, M — дробова.
 * Таблиця покриває всі стандартні FPV діапазони:
 *   Індекс діапазону 0=Band A, 1=Band B, 2=Band E, 3=Band F(Fatshark), 4=Band R(Raceband)
 */
const uint16_t channelFreqTable[5][8] = {
  // Band A (Boscam A)
  { 5865, 5845, 5825, 5805, 5785, 5765, 5745, 5725 },
  // Band B (Boscam B)
  { 5733, 5752, 5771, 5790, 5809, 5828, 5847, 5866 },
  // Band E (DJI / Immersion)
  { 5705, 5685, 5665, 5645, 5885, 5905, 5925, 5945 },
  // Band F (Fatshark)
  { 5740, 5760, 5780, 5800, 5820, 5840, 5860, 5880 },
  // Band R (Raceband)
  { 5658, 5695, 5732, 5769, 5806, 5843, 5880, 5917 }
};

/*
 * 20-бітні SPI-слова для кожного каналу.
 * Формула: spiWord = ((F / 2) / 32) | (((F / 2) % 32) << 7)
 * Але простіше — використати готову таблицю нижче.
 *
 * Джерело: https://github.com/Marko-Bernbaum/rx5808-pro-diversity
 * (перевірені значення, сумісні з RX5808)
 */
const uint32_t channelSpiTable[5][8] = {
  // Band A
  { 0x282C, 0x2800, 0x27D4, 0x27A8, 0x277C, 0x2750, 0x2724, 0x26F8 },
  // Band B
  { 0x2596, 0x260C, 0x2682, 0x26F8, 0x276E, 0x27E4, 0x285A, 0x28D0 },
  // Band E
  { 0x246C, 0x2440, 0x2414, 0x23E8, 0x2904, 0x297A, 0x29F0, 0x2A66 },
  // Band F
  { 0x2606, 0x267C, 0x26F2, 0x2768, 0x27DE, 0x2854, 0x28CA, 0x2940 },
  // Band R
  { 0x2362, 0x23D8, 0x244E, 0x24C4, 0x253A, 0x25B0, 0x2626, 0x269C }
};

// ─── СТАН ПРОГРАМИ ───────────────────────────────────────────
uint8_t currentBand    = 4;  // Починаємо з Raceband (найпопулярніший)
uint8_t currentChannel = 0;  // Канал 1 (індекс 0)
bool    autoScanActive = false;

// Для дебаунсингу кнопок (апаратний RC вже є, але додаємо програмний)
uint32_t lastBtnTime = 0;
#define BTN_DEBOUNCE_MS  50

// Для автосканування
uint8_t  scanBand    = 0;
uint8_t  scanChannel = 0;
uint32_t scanTimer   = 0;
#define SCAN_SETTLE_MS  50    // Час стабілізації після перемикання (мс)
#define SCAN_SAMPLES     5    // Кількість зчитувань RSSI для усереднення

uint16_t bestRssi    = 0;
uint8_t  bestBand    = 0;
uint8_t  bestChan    = 0;

// Для виводу в Serial (щоб не спамити)
uint32_t lastPrintTime = 0;
#define PRINT_INTERVAL_MS  500

// ─── ПРОТОТИПИ ФУНКЦІЙ ───────────────────────────────────────
void     rx5808_SetFrequency(uint8_t band, uint8_t channel);
void     rx5808_SpiWrite(uint32_t data, uint8_t bits);
uint16_t rssi_Read(void);
uint16_t rssi_ReadAverage(uint8_t samples);
void     bq25703a_InitADC(void);
float    bq25703a_ReadVbat(void);
void     printStatus(void);
void     startAutoScan(void);
bool     autoScanStep(void);

// =============================================================
//  SETUP
// =============================================================
void setup() {
  Serial.begin(115200);
  Serial.println(F("================================="));
  Serial.println(F("  FPV Receiver RX5808 v1.0"));
  Serial.println(F("================================="));

  // Налаштування SPI пінів (bit-bang)
  pinMode(PIN_SPI_MOSI, OUTPUT);
  pinMode(PIN_SPI_CS,   OUTPUT);
  pinMode(PIN_SPI_SCK,  OUTPUT);
  digitalWrite(PIN_SPI_CS,  HIGH);  // CS неактивний
  digitalWrite(PIN_SPI_SCK, LOW);
  digitalWrite(PIN_SPI_MOSI,LOW);

  // RSSI — аналоговий вхід (ADC6 не потребує pinMode)

  // Кнопки — INPUT_PULLUP (кнопки підтягнуті до +3.3V через 10K на схемі,
  // але внутрішній pullup не зашкодить як резервний)
  pinMode(PIN_BTN_UP,   INPUT_PULLUP);
  pinMode(PIN_BTN_DOWN, INPUT_PULLUP);
  pinMode(PIN_BTN_SCAN, INPUT_PULLUP);

  // I2C для BQ25703A
  Wire.begin();
  delay(100);
  bq25703a_InitADC();  // Запускаємо ADC вимірювання в зарядника

  // Встановлюємо початкову частоту
  Serial.print(F("Встановлюємо початковий канал: Band R, CH1 ("));
  Serial.print(channelFreqTable[currentBand][currentChannel]);
  Serial.println(F(" MHz)"));

  rx5808_SetFrequency(currentBand, currentChannel);
  delay(50);  // Час стабілізації PLL

  Serial.println(F("Готово! Керування:"));
  Serial.println(F("  SW1 (D5) = Канал ▲"));
  Serial.println(F("  SW2 (D6) = Канал ▼"));
  Serial.println(F("  SW3 (D7) = Автосканування"));
  Serial.println(F("---------------------------------"));
}

// =============================================================
//  LOOP
// =============================================================
void loop() {
  uint32_t now = millis();

  // ── Обробка кнопок ─────────────────────────────────────────
  if ((now - lastBtnTime) > BTN_DEBOUNCE_MS) {

    // SW1 — Канал вгору
    if (digitalRead(PIN_BTN_UP) == LOW) {
      lastBtnTime = now;
      autoScanActive = false;

      currentChannel++;
      if (currentChannel >= 8) {
        currentChannel = 0;
        currentBand++;
        if (currentBand >= 5) currentBand = 0;
      }

      rx5808_SetFrequency(currentBand, currentChannel);
      Serial.print(F("▲ Band "));
      Serial.print(currentBand);
      Serial.print(F(" CH"));
      Serial.print(currentChannel + 1);
      Serial.print(F(" — "));
      Serial.print(channelFreqTable[currentBand][currentChannel]);
      Serial.println(F(" MHz"));

      // Чекаємо поки кнопку відпустять
      while (digitalRead(PIN_BTN_UP) == LOW) delay(10);
    }

    // SW2 — Канал вниз
    else if (digitalRead(PIN_BTN_DOWN) == LOW) {
      lastBtnTime = now;
      autoScanActive = false;

      if (currentChannel == 0) {
        currentChannel = 7;
        if (currentBand == 0) currentBand = 4;
        else currentBand--;
      } else {
        currentChannel--;
      }

      rx5808_SetFrequency(currentBand, currentChannel);
      Serial.print(F("▼ Band "));
      Serial.print(currentBand);
      Serial.print(F(" CH"));
      Serial.print(currentChannel + 1);
      Serial.print(F(" — "));
      Serial.print(channelFreqTable[currentBand][currentChannel]);
      Serial.println(F(" MHz"));

      while (digitalRead(PIN_BTN_DOWN) == LOW) delay(10);
    }

    // SW3 — Старт/Стоп автосканування
    else if (digitalRead(PIN_BTN_SCAN) == LOW) {
      lastBtnTime = now;

      if (!autoScanActive) {
        Serial.println(F("⟳ Автосканування запущено..."));
        startAutoScan();
      } else {
        autoScanActive = false;
        Serial.println(F("⏹ Автосканування зупинено"));
      }

      while (digitalRead(PIN_BTN_SCAN) == LOW) delay(10);
    }
  }

  // ── Автосканування ─────────────────────────────────────────
  if (autoScanActive) {
    if ((now - scanTimer) >= SCAN_SETTLE_MS) {
      scanTimer = now;
      bool done = autoScanStep();

      if (done) {
        autoScanActive = false;
        currentBand    = bestBand;
        currentChannel = bestChan;

        Serial.println(F("✓ Найкращий сигнал знайдено:"));
        Serial.print(F("  Band "));
        Serial.print(currentBand);
        Serial.print(F(" CH"));
        Serial.print(currentChannel + 1);
        Serial.print(F(" — "));
        Serial.print(channelFreqTable[currentBand][currentChannel]);
        Serial.print(F(" MHz, RSSI="));
        Serial.println(bestRssi);

        rx5808_SetFrequency(currentBand, currentChannel);
      }
    }
  }

  // ── Вивід статусу в Serial кожні 500мс ────────────────────
  if ((now - lastPrintTime) >= PRINT_INTERVAL_MS) {
    lastPrintTime = now;
    if (!autoScanActive) {
      printStatus();
    }
  }
}

// =============================================================
//  RX5808: ВСТАНОВЛЕННЯ ЧАСТОТИ ЧЕРЕЗ BIT-BANG SPI
// =============================================================
/*
 * Протокол RX5808 (нестандартний):
 *  1. Підтягуємо CS HIGH → LOW (початок транзакції)
 *  2. Передаємо 4 біти адреси регістру (LSB першим)
 *  3. Передаємо 1 біт: 1=запис, 0=читання
 *  4. Передаємо 20 біт даних (LSB першим)
 *  5. CS → HIGH (кінець транзакції)
 *
 *  Регістр синтезатора: адреса 0x01
 */
void rx5808_SetFrequency(uint8_t band, uint8_t channel) {
  uint32_t spiData = channelSpiTable[band][channel];

  // Адреса регістру синтезатора = 0x01, команда запису = 1
  // Пакет: [4 біти адреси] + [1 біт запис] + [20 біт даних] = 25 біт
  uint32_t packet = 0;
  // Адреса 0x01 (4 біти, LSB першим): 1000
  packet |= (uint32_t)0x01;       // Біти 0-3: адреса
  packet |= (uint32_t)1 << 4;     // Біт 4: запис
  packet |= (uint32_t)(spiData & 0xFFFFF) << 5;  // Біти 5-24: дані (20 біт)

  digitalWrite(PIN_SPI_CS, LOW);
  delayMicroseconds(1);

  rx5808_SpiWrite(packet, 25);

  delayMicroseconds(1);
  digitalWrite(PIN_SPI_CS, HIGH);
}

/*
 * Передача бітів по SPI (LSB першим, CPOL=0, CPHA=0)
 */
void rx5808_SpiWrite(uint32_t data, uint8_t bits) {
  for (uint8_t i = 0; i < bits; i++) {
    digitalWrite(PIN_SPI_MOSI, (data >> i) & 1);
    delayMicroseconds(1);
    digitalWrite(PIN_SPI_SCK, HIGH);
    delayMicroseconds(1);
    digitalWrite(PIN_SPI_SCK, LOW);
    delayMicroseconds(1);
  }
  digitalWrite(PIN_SPI_MOSI, LOW);
}

// =============================================================
//  RSSI: ЗЧИТУВАННЯ РІВНЯ СИГНАЛУ
// =============================================================
/*
 * ADC6 на ATmega328P — лише аналоговий вхід (без цифрової функції).
 * Значення 0–1023: 0 = 0V, 1023 = 3.3V (AVCC).
 * Типовий RSSI від RX5808: ~0.5V (немає сигналу) — ~1.8V (сильний сигнал).
 * Відповідно: ~155 (немає) — ~560 (сильний).
 */
uint16_t rssi_Read(void) {
  return analogRead(PIN_RSSI);
}

uint16_t rssi_ReadAverage(uint8_t samples) {
  uint32_t sum = 0;
  for (uint8_t i = 0; i < samples; i++) {
    sum += analogRead(PIN_RSSI);
    delay(2);
  }
  return (uint16_t)(sum / samples);
}

// =============================================================
//  АВТОСКАНУВАННЯ
// =============================================================
void startAutoScan(void) {
  autoScanActive = true;
  scanBand    = 0;
  scanChannel = 0;
  bestRssi    = 0;
  bestBand    = 0;
  bestChan    = 0;
  scanTimer   = millis() - SCAN_SETTLE_MS;  // Одразу перший крок

  rx5808_SetFrequency(scanBand, scanChannel);
}

/*
 * Один крок сканування. Повертає true коли всі канали перебрано.
 */
bool autoScanStep(void) {
  // Зчитуємо RSSI поточного каналу (вже дочекались SCAN_SETTLE_MS)
  uint16_t rssi = rssi_ReadAverage(SCAN_SAMPLES);

  Serial.print(F("  Скан B"));
  Serial.print(scanBand);
  Serial.print(F(" CH"));
  Serial.print(scanChannel + 1);
  Serial.print(F(" ("));
  Serial.print(channelFreqTable[scanBand][scanChannel]);
  Serial.print(F(" MHz) RSSI="));
  Serial.println(rssi);

  if (rssi > bestRssi) {
    bestRssi = rssi;
    bestBand = scanBand;
    bestChan = scanChannel;
  }

  // Наступний канал
  scanChannel++;
  if (scanChannel >= 8) {
    scanChannel = 0;
    scanBand++;
    if (scanBand >= 5) {
      return true;  // Всі канали перебрано
    }
  }

  // Встановлюємо наступну частоту (стабілізація відбудеться через SCAN_SETTLE_MS)
  rx5808_SetFrequency(scanBand, scanChannel);
  return false;
}

// =============================================================
//  BQ25703A: ІНІЦІАЛІЗАЦІЯ ADC ТА ЧИТАННЯ НАПРУГИ БАТАРЕЇ
// =============================================================
/*
 * BQ25703A — 20-бітний I2C зарядник для 1-4 cells.
 * Для читання VBAT треба спочатку включити ADC вимірювання.
 * Регістр ADC_OPTION (0x3A): біт 7 = ADC_START (одиночне вимірювання),
 * або біт 6 = ADC_FULLSCALE + біт 7 для безперервного.
 *
 * ВАЖЛИВО: BQ25703A використовує 16-бітні регістри.
 */
void bq25703a_InitADC(void) {
  // Перевіряємо чи є BQ25703A на шині
  Wire.beginTransmission(BQ25703A_ADDR);
  uint8_t err = Wire.endTransmission();

  if (err != 0) {
    Serial.println(F("⚠ BQ25703A не знайдено на I2C (адреса 0x6B)"));
    Serial.println(F("  Перевірте: живлення, підтяжки SDA/SCL, пайку"));
    return;
  }

  Serial.println(F("✓ BQ25703A знайдено"));

  // Включаємо ADC: IBAT disable, PSYS disable, VBUS enable, IDCHG enable
  // Регістр ADC_OPTION (0x3A), встановлюємо безперервний режим ADC
  // Байт LSB: EN_ADC_VBAT(bit1)=1, EN_ADC_VSYS(bit0)=1
  // Байт MSB: ADC_CONV(bit7)=1 (безперервне)
  Wire.beginTransmission(BQ25703A_ADDR);
  Wire.write(REG_ADC_OPTION);    // Адреса регістру
  Wire.write(0x03);              // LSB: увімкнути VBAT та VSYS ADC
  Wire.write(0x80);              // MSB: безперервний режим
  Wire.endTransmission();

  delay(100);  // Чекаємо першого перетворення
  Serial.println(F("✓ BQ25703A ADC запущено"));
}

/*
 * Читаємо напругу батареї (VBAT) в вольтах.
 * Регістр ADCVBAT: 8 біт (тільки MSB, LSB=0).
 * Формула: Vbat = 2.88V + значення * 64mV (згідно datasheet BQ25703A)
 */
float bq25703a_ReadVbat(void) {
  // Запит регістру ADCVBAT_MSB (0x2B)
  Wire.beginTransmission(BQ25703A_ADDR);
  Wire.write(REG_ADCVBAT_MSB);
  Wire.endTransmission(false);  // Repeated start

  Wire.requestFrom(BQ25703A_ADDR, (uint8_t)1);
  if (Wire.available()) {
    uint8_t raw = Wire.read();
    // Формула з datasheet: VBAT(V) = 2.88 + raw * 0.064
    return 2.88f + (float)raw * 0.064f;
  }
  return 0.0f;
}

/*
 * Приблизний відсоток заряду Li-Ion/Li-Po 2S батареї.
 * 2S повністю заряджена: 8.4V (4.2V * 2)
 * 2S повністю розряджена: 6.0V (3.0V * 2) — безпечна межа
 */
uint8_t batteryPercent(float vbat) {
  if (vbat >= 8.4f) return 100;
  if (vbat <= 6.0f) return 0;
  return (uint8_t)((vbat - 6.0f) / (8.4f - 6.0f) * 100.0f);
}

// =============================================================
//  ВИВІД СТАТУСУ В SERIAL MONITOR
// =============================================================
void printStatus(void) {
  uint16_t rssi = rssi_ReadAverage(3);
  float    vbat = bq25703a_ReadVbat();

  // Назви діапазонів
  const char* bandNames[] = { "A", "B", "E", "F", "R" };

  Serial.print(F("Band "));
  Serial.print(bandNames[currentBand]);
  Serial.print(F(" CH"));
  Serial.print(currentChannel + 1);
  Serial.print(F(" | "));
  Serial.print(channelFreqTable[currentBand][currentChannel]);
  Serial.print(F(" MHz | RSSI: "));
  Serial.print(rssi);

  // Проста шкала сигналу
  Serial.print(F(" ["));
  uint8_t bars = map(rssi, 0, 1023, 0, 10);
  for (uint8_t i = 0; i < 10; i++) {
    Serial.print(i < bars ? '|' : '.');
  }
  Serial.print(F("] | Bat: "));

  if (vbat > 0.0f) {
    Serial.print(vbat, 2);
    Serial.print(F("V ("));
    Serial.print(batteryPercent(vbat));
    Serial.print(F("%)"));

    // Попередження про низький заряд
    if (vbat < 6.6f) {
      Serial.print(F(" ⚠ НИЗЬКИЙ ЗАРЯД!"));
    }
  } else {
    Serial.print(F("N/A"));
  }

  Serial.println();
}

/*
 * =============================================================
 *  ІНСТРУКЦІЯ З ПРОШИВКИ:
 * =============================================================
 *
 *  ВАРІАНТ А — Через USB (CP2102N, простіший):
 *  1. Підключи плату до комп'ютера через USB Type-C
 *  2. В Arduino IDE:
 *     - Плата: "Arduino Uno" або "Arduino Nano" (залежно від bootloader)
 *     - Порт: вибери COM-порт CP2102N
 *     - Якщо використовуєш "Arduino Nano": Процесор = "ATmega328P (Old Bootloader)"
 *  3. Скетч → Завантажити (Ctrl+U)
 *
 *  ВАРІАНТ Б — Через ICSP (J5, якщо bootloader не прошитий):
 *  1. Підключи USBASP або інший AVR ISP до роз'єму J5
 *     J5 розпіновка (стандарт AVR ICSP 2x3):
 *       1=MISO  2=VCC
 *       3=SCK   4=MOSI
 *       5=RST   6=GND
 *  2. В Arduino IDE: Інструменти → Програматор → USBasp
 *  3. Спочатку: Інструменти → Записати завантажувач (щоб встановити Fuses)
 *  4. Потім: Скетч → Завантажити через програматор
 *
 *  FUSE BITS для ATmega328P (16 MHz кварц):
 *     Low:  0xFF  (зовнішній кварц 8+ MHz)
 *     High: 0xDE  (SPIEN, bootloader 512 bytes)
 *     Ext:  0xFD
 *
 *  SERIAL MONITOR: 115200 baud, NL+CR
 * =============================================================
 */

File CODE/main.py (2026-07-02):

import sys
import re
import collections
import serial
from PyQt5 import QtWidgets, QtCore
import pyqtgraph as pg

# =====================================================================
# НАЛАШТУВАННЯ ПОРТУ
# =====================================================================
SERIAL_PORT = 'COM5'  # Твій робочий порт Arduino Nano
BAUD_RATE   = 115200
MAX_POINTS  = 150     # Кількість точок на діаграмі (ширина розгортки екрана)

class RSSILiveDiagram(QtWidgets.QWidget):
    def init(self):
        super().init()
        
        # Підключення до Arduino Nano
        try:
            self.ser = serial.Serial(SERIAL_PORT, BAUD_RATE, timeout=0.01)
        except Exception as e:
            print(f"Помилка відкриття порту {SERIAL_PORT}: {e}")
            print("Переконайся, що Монітор порту в Arduino IDE закритий!")
            sys.exit(1)
            
        # Кільцевий буфер для збереження історії значень RSSI
        self.rssi_data = collections.deque([0] * MAX_POINTS, maxlen=MAX_POINTS)
        self.x_axis = list(range(MAX_POINTS))
        
        # Парсери рядків Serial порту
        self.status_pattern = re.compile(r"RSSI:\s*(\d+)")
        self.best_pattern   = re.compile(r"RSSI=(\d+)")
        
        self.info_text = "Очікування сигналу від RX5808..."
        
        self.init_layout()
        
        # Таймер для оновлення діаграми: 40 мс = 25 кадрів на секунду (FPS)
        self.ui_timer = QtCore.QTimer()
        self.ui_timer.setInterval(40) 
        self.ui_timer.timeout.connect(self.refresh_diagram)
        self.ui_timer.start()

    def init_layout(self):
        self.setWindowTitle('FPV RSSI Real-Time Diagram')
        self.resize(900, 500)
        self.setStyleSheet("background-color: #141414; color: #E0E0E0;")
        
        main_layout = QtWidgets.QVBoxLayout()
        
        # Текстове табло над діаграмою
        self.label_status = QtWidgets.QLabel(self.info_text)
        self.label_status.setStyleSheet("font-size: 18px; font-family: monospace; font-weight: bold; color: #00FFCC; padding: 5px;")
        main_layout.addWidget(self.label_status)
        
        # Налаштування віджета діаграми pyqtgraph
        self.graph_widget = pg.PlotWidget()
        self.graph_widget.setBackground('#1A1A1A')
        
        # Стилізація сітки діаграми
        self.graph_widget.showGrid(x=True, y=True, alpha=0.25)
        self.graph_widget.setYRange(0, 700)  # Максимальна межа АЦП Arduino (~700)
        
        # Назви осей
        self.graph_widget.setLabel('left', 'Потужність сигналу (RSSI)', color='#A0A0A0')
        self.graph_widget.setLabel('bottom', 'Часова шкала (останні семпли)', color='#A0A0A0')
        
        # Створення лінії діаграми (яскравий колір, товщина лінії = 2.5)
        chart_pen = pg.mkPen(color='#00FFCC', width=2.5)
        self.curve = self.graph_widget.plot(self.x_axis, list(self.rssi_data), pen=chart_pen)
        
        main_layout.addWidget(self.graph_widget)
        self.setLayout(main_layout)

    def refresh_diagram(self):
        try:
            # Вигрібаємо всі дані з буфера порту, щоб уникнути накопичення затримок
            while self.ser.in_waiting > 0:
                raw_line = self.ser.readline().decode('utf-8', errors='ignore').strip()
                if not raw_line:
                    continue
                
                # Пошук стандартного виводу стану
                match_status = self.status_pattern.search(raw_line)
                if match_status:
                    val = int(match_status.group(1))
                    self.rssi_data.append(val)
                    
                    # Залишаємо інформаційну частину рядка без символів [|||...]
                    self.info_text = f"📡 {raw_line.split('[')[0].strip()}"
                    continue
                
                # Пошук результату автосканування
                match_best = self.best_pattern.search(raw_line)
                if match_best:
                    val = int(match_best.group(1))
                    self.rssi_data.append(val)
                    self.info_text = f"🏆 Знайдено: {raw_line}"
                    continue
                
                # Якщо йде сканування
                if raw_line.startswith('.') or "Scanning" in raw_line:
                    self.info_text = "🔍 Сканування всіх 40 каналів..."
                    
        except Exception as serial_err:
            self.info_text = f"Помилка прийому: {serial_err}"

        # Оновлюємо текстову інформацію та малюємо нову точку на діаграмі
        self.label_status.setText(self.info_text)
        self.curve.setData(self.x_axis, list(self.rssi_data))

    def closeEvent(self, event):
        if self.ser.isOpen():
            self.ser.close()
        event.accept()

if name == 'main':
    app = QtWidgets.QApplication(sys.argv)
    diagram = RSSILiveDiagram()
    diagram.show()
    sys.exit(app.exec_())  # Виправлений запуск головного циклу

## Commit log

2026-05-17 init
    added simple structure with minimal PCB
    [BQ25703ARSNR.step, CP2102N-A02-GQFN28.step, RX.kicad_sch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]
2026-05-18 fixed positions
    [atmega328.kicad_pcb]
2026-05-18 fixed positions 2
    [atmega328.kicad_pcb]
2026-05-19 fixed all errors and warnings
    [atmega328.kicad_pcb]
2026-05-21 added connections
    [atmega328.kicad_pcb]
2026-05-21 fixed positions of connections
    [atmega328.kicad_pcb]
2026-05-21 added JLCPCB settings
    [atmega328.kicad_pcb]
2026-05-23 Force update local files
    [atmega328.kicad_pcb, mcu_atmega_spi.kicad_sch, power_usb_battery_buck.kicad_sch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]
2026-05-24 done with lcsc
    [atmega328.kicad_pcb, mcu_atmega_spi.kicad_sch, power_usb_battery_buck.kicad_sch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]
2026-07-02 added images
    [mcu_atmega_spi.kicad_sch]
